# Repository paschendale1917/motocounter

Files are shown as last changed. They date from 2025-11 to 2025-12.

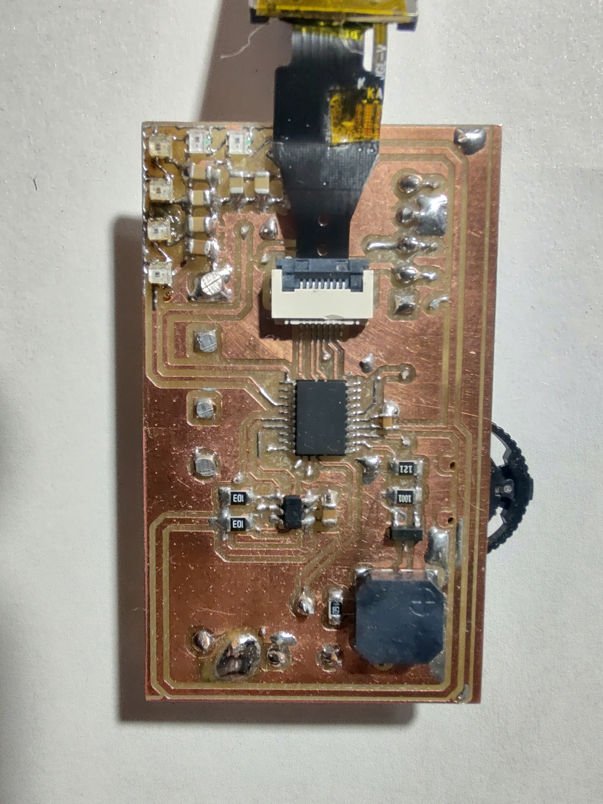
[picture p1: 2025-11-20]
IMG_20251120_144156860_HDR.jpg

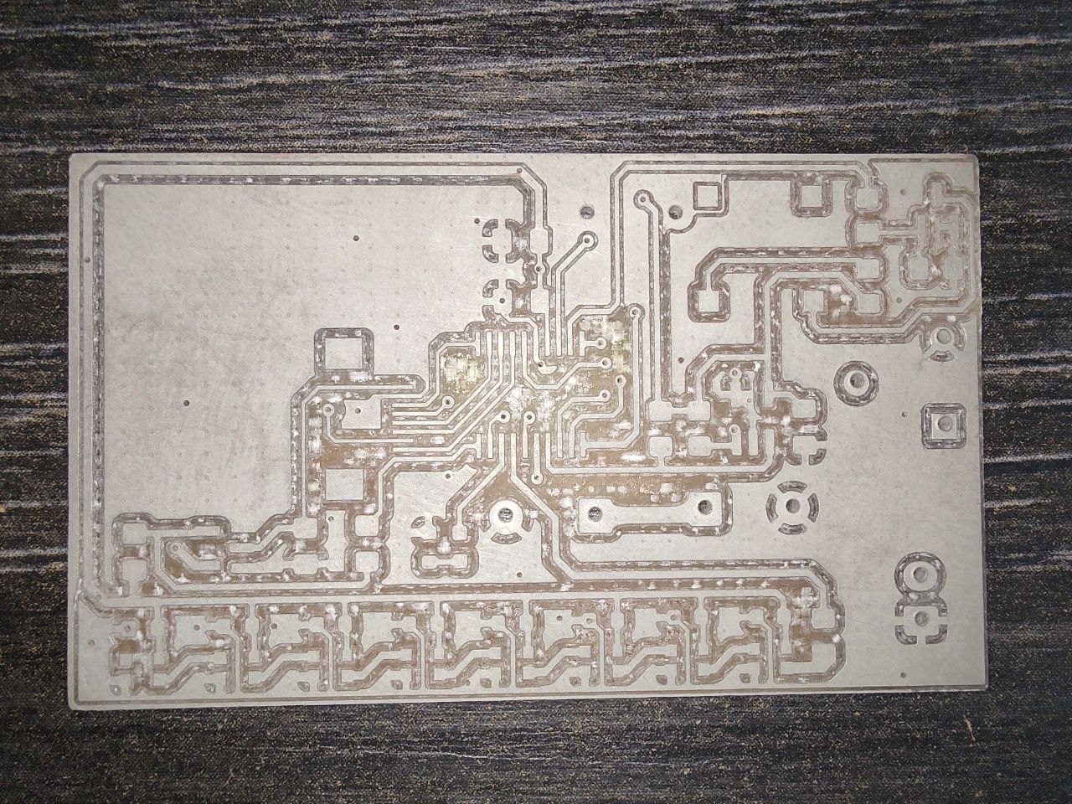
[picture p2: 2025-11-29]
photo_2025-11-30_00-51-48.jpg

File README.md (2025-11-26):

###	Счетчик моточасов с системой меню и управлением с помощью трехпозиционного слайдера

- **Микроконтроллер:** STM32G030F6P6 
- **Частота:** 64 МГц
- **IDE:** Keil uVision
- **Compiler:** v6.19
- **Язык:** C (Embedded)
- **Дисплей:** LCD ST7735 0.96" 80_160(IPS), 1.8" 128_160(TN), 0.85" 128_128(IPS)
- **Задействованная периферия:** таймеры, АЦП, SPI, I2C, DMA
- **Управление:** Трехпозиционная кнопка(слайдер)
- **Программатор:** ST-Link v2

###	Больше по дисплею
- можно любой на драйвере ST7735, но в дефайнах изменить разрешение, а также параметры LCD_HEIGHT_OFFSET и LCD_WIDTH_OFFSET выставить на 0, либо подобрать свои смещения
- возможно придется поиграться с регистрами MADCTL и INVON/INVOFF дисплея для установки верной ориентации и режима отображения цветов

###	Больше по периферии
- Нажатия слайдера обрабатываются в прерываниях таймера TIM1. Распознаются длительные и короткие нажатия
- Подсветка дисплея использует таймер TIM14  в режиме ШИМ
- Баззер использует таймер TIM17 в режиме ШИМ
- Счетчик организован на таймере TIM16
- Светодиоды WS2812 используют таймер TIM3 и канал 1 DMA1
- Вольтметр использует канал 10 мультиплексора АЦП и канал 2 DMA1
- Дисплей на SPI1
- EEPROM на I2C2
- WWDG

###	Клонирование репозитория
git clone https://github.com/paschendale1917/motocounter.git

###	Принцип работы:
После подачи питания устройство считывает из EEPROM настроечные константы, измеряет напряжение в бортовой сети и отображает на главном экране
 количество наработанных моточасов,напряжение бортовой сети и уставку моточасов, при достижении значения которой счетчик будет подавать светозвуковой сигнал.
При заведенном двигателе напряжение в бортовой сети повышается и при достижении порогового значения начинается отсчет времени.
Из меню можно настроить:
- величину порогового значения напряжения в бортовой сети для старта отсчета времени наработки
- уставку моточасов для подачи светозвуковой сигнализации при превышении счетчиком ее значения
- величину значения делителя(для того, чтобы не разбирать корпус и не подстраивать потенциометр на входе АЦП)
- цвет индикации превышения значения счетчика уставки моточасов
- яркость подсветки дисплея

При снижении напряжения питания ниже порогового значения прекращается отсчет времени и производится запись значения счетчика в EEPROM.
Все остальные настраиваемые константы также сохраняются в EEPROM.
Для того, чтобы при резком отключении питания была возможность сохранения всех настроек и значения счетчика, на входе по питанию установлены 2 конденсатора по 1000 мкФ. 
Через минуту после последней активности органов управления подсветка дисплея снижается до минимума.
 
###	Управление:
- вход в меню из главного экрана по длительному нажатию на центр слайдера
- выход из меню на скринсейвер по длительному отклонению слайдера влево
- вход в дочернее меню (child) по короткому нажатию на центр слайдера
- выход в родительское меню (parent) по длительному отклонению слайдера влево
- вход в обработчик пункта меню по короткому нажатию на центр слайдера
- выход из обработчика пункта меню по длительному отклонению слайдера влево
- согласие на системный ресет или сброс счетчика моточасов по длительному отклонению слайдера вправо

###	Краткое описание системы меню:
- Создана структура, в которой описаны связи пунктов меню(двунаправленные связные списки)между друг другом и обработчиками состояния меню(КА).
- В бесконечном цикле мониторится состояние переменной menustate(состояние меню),состояние флагов органов управления, отслеживаются изменения в состоянии меню,которое перерисовывается в соответствии с этими изменениями. 
	Также здесь работает функция display_pointer(pointer), которая меняет положение указателя в соответствии с активным пунктом меню(всегда указывает на него). Координаты указателя явно заданы в структуре. 
	Всё это происходит до того момента, пока переменная menustate не примет значение, соответствующее номеру одного из обработчиков.
- Как только зафиксировано изменение в состоянии органов управления(нажатие кнопки или вращение вала энкодера), то происходит действие в соответствии с заданным функционалом в process_menu() и связями, установленными 
	в структуре пункта меню-это либо вход в обработчик, либо в дочернее меню, либо перемещение по меню.
- При входе в обработчик в переменную menustate записывается его номер и таким образом process_menu() передает ему управление. Далее программа действует в соответствии с внутренней логикой обработчика.
- При выходе из обработчика в переменную menustate записывается значение, не соответствующее ни одному из номеров обработчиков, что возвращает управление функции process_menu().
- При старте в переменной menustate записан 0, что соответствует обработчику скринсейвера.
 
###	Внимание!
- Уверенно измеряет напряжение от 7 до 22 вольт, чтобы изменить диапазон, требуется подобрать иную элементную базу
- Нужно помнить, что чем выше входное напряжение, тем выше нагрев(78M05), поэтому беспроблемная эксплуатация возможна только на легковом 
 автомобиле с номинальным напряжением бортовой сети 12 в

###	TO DO:
- ...

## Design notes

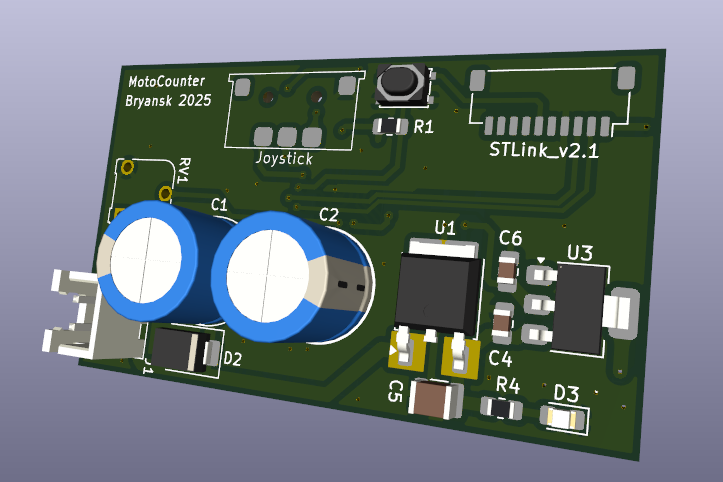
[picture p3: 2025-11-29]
Screenshot_2.png

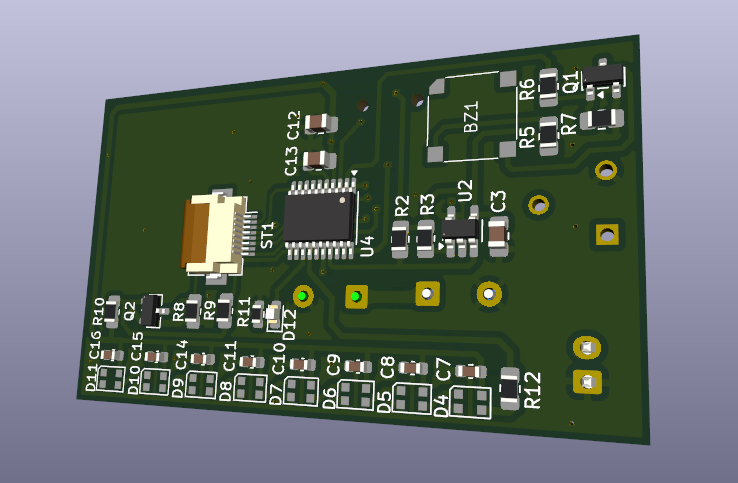
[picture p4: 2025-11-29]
Screenshot_1.png

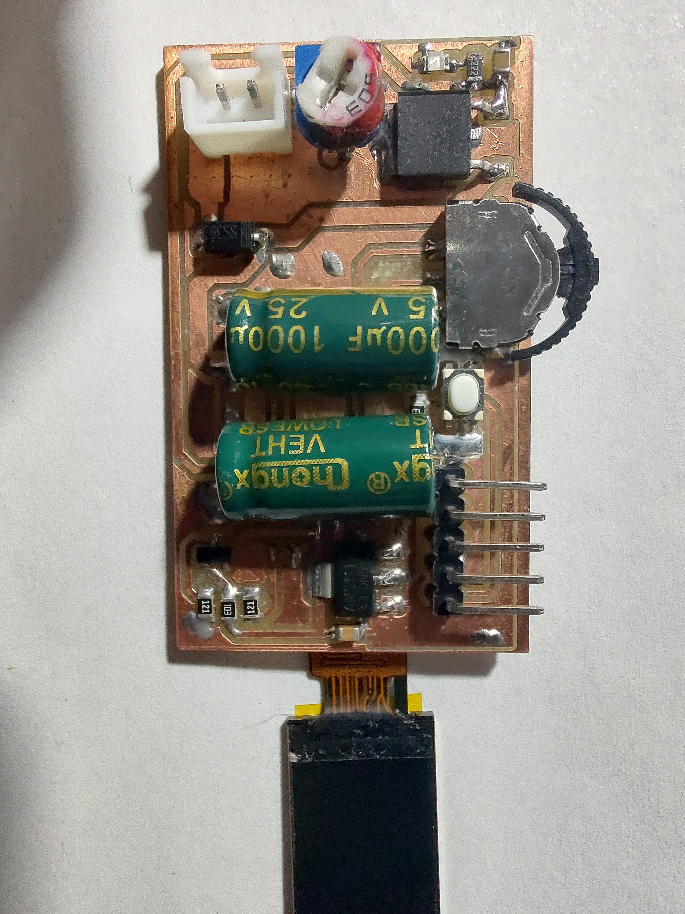
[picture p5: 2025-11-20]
IMG_20251120_144207942_HDR.jpg

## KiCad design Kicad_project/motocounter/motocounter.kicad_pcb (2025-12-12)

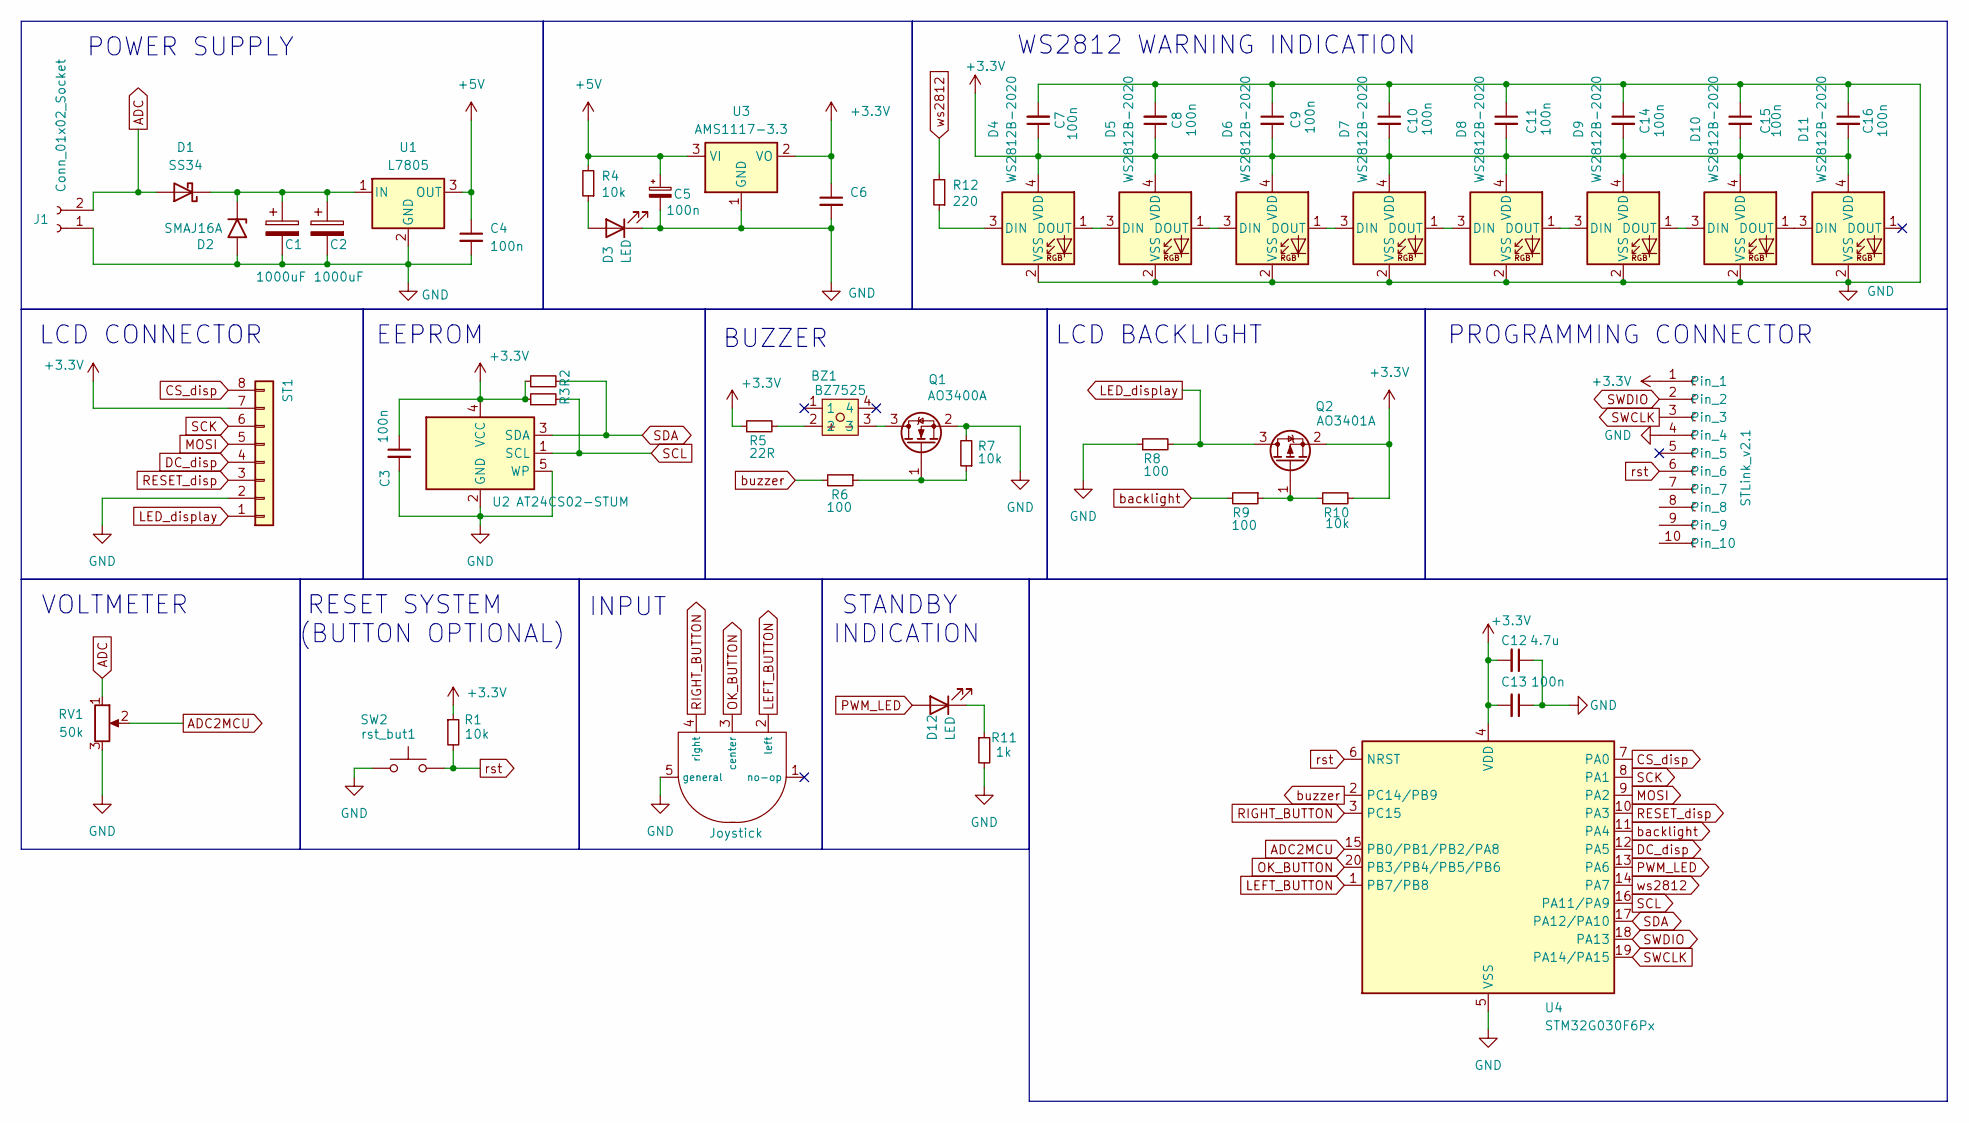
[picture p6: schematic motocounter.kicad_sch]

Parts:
BZ1: BZ7525; Buzzer_7525
C1, C2: 1000uF; CP_Radial_D10.0mm_P5.00mm
C3, C4, C13: 100n; C_0805_2012Metric_Pad1.18x1.45mm_HandSolder
C5: 100n; C_1210_3225Metric
C6: 2.2uF; C_0805_2012Metric_Pad1.18x1.45mm_HandSolder
C7, C8, C9, C10, C11, C14, C15, C16: 100n; C_0603_1608Metric
C12: 4.7u; C_0805_2012Metric_Pad1.18x1.45mm_HandSolder
D1: SS34; D_SMA
D2: SMAJ16A; D_SMB
D3: LED; LED_0805_2012Metric_Pad1.15x1.40mm_HandSolder
D4, D5, D6, D7, D8, D9, D10, D11: WS2812B-2020; LED_WS2812B-2020_PLCC4_2.0x2.0mm
D12: LED; LED_0603_1608Metric
J1: Conn_01x02_Socket; JST_XH_B2B-XH-A_1x02_P2.50mm_Vertical
Joystick: slide_button
Q1: AO3400A; SOT-23
Q2: AO3401A; SOT-23
R1, R2, R3, R4, R7, R10: 10k; R_0805_2012Metric_Pad1.20x1.40mm_HandSolder
R5: 22R; R_0805_2012Metric_Pad1.20x1.40mm_HandSolder
R6, R8, R9: 100; R_0805_2012Metric_Pad1.20x1.40mm_HandSolder
R11: 1k; R_0603_1608Metric
R12: 220; R_0805_2012Metric_Pad1.20x1.40mm_HandSolder
RV1: 50k; Potentiometer_Runtron_RM-065_Vertical
ST1: display; Hirose_FH12-8S-0.5SH_1x08-1MP_P0.50mm_Horizontal
STLink_v2.1: JST_SH_SM10B-SRSS-TB_1x10-1MP_P1.00mm_Horizontal
U1: L7805; TO-252-2
U2: AT24CS02-STUM; SOT-23-5_HandSoldering
U3: AMS1117-3.3; SOT-223-3_TabPin2
U4: STM32G030F6Px; TSSOP-20_4.4x6.5mm_P0.65mm
rst_but1: SW2; SW_SPST_PTS810

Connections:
+3.3V: C3.1, C6.1, C7.1, C8.1, C9.2, C10.2, C11.2, C12.2, C13.2, C14.2, C15.2, C16.2, D4.4 (VDD), D5.4 (VDD), D6.4 (VDD), D7.4 (VDD), D8.4 (VDD), D9.4 (VDD), D10.4 (VDD), D11.4 (VDD), Q2.2 (S), R1.1, R2.1, R3.1, R5.1, R10.2, ST1.7, STLink_v2.1.1, U2.4 (VCC), U3.2 (VO), U4.4 (VDD)
+5V: C4.1, C5.1, R4.2, U1.3 (OUT), U3.3 (VI)
ADC: D1.2 (A), J1.2, RV1.1
ADC2MCU: RV1.2, U4.15 (PB0/PB1/PB2/PA8)
CS_disp: ST1.8, U4.7 (PA0)
DC_disp: ST1.4, U4.12 (PA5)
GND: C1.2, C2.2, C3.2, C4.2, C5.2, C6.2, C7.2, C8.2, C9.1, C10.1, C11.1, C12.1, C13.1, C14.1, C15.1, C16.1, D2.2 (A2), D3.1 (K), D4.2 (VSS), D5.2 (VSS), D6.2 (VSS), D7.2 (VSS), D8.2 (VSS), D9.2 (VSS), D10.2 (VSS), D11.2 (VSS), J1.1, Joystick.5 (general), Q1.2 (S), R7.2, R8.1, R11.2, RV1.3, ST1.2, STLink_v2.1.4, U1.2 (GND), U2.2 (GND), U2.5 (WP), U3.1 (GND), U4.5 (VSS), rst_but1.1
LED_display: Q2.3 (D), R8.2, ST1.1
LEFT_BUTTON: Joystick.2 (left), U4.1 (PB7/PB8)
MOSI: ST1.5, U4.9 (PA2)
unnamed: BZ1.2, R5.2
unnamed: C1.1, C2.1, D1.1 (K), D2.1 (A1), U1.1 (IN)
unnamed: D3.2 (A), R4.1
unnamed: D4.3 (DIN), R12.1
unnamed: D4.1 (DOUT), D5.3 (DIN)
unnamed: D5.1 (DOUT), D6.3 (DIN)
unnamed: D6.1 (DOUT), D7.3 (DIN)
unnamed: D7.1 (DOUT), D8.3 (DIN)
unnamed: D8.1 (DOUT), D9.3 (DIN)
unnamed: D9.1 (DOUT), D10.3 (DIN)
unnamed: D10.1 (DOUT), D11.3 (DIN)
unnamed: D12.1 (K), R11.1
unnamed: BZ1.3, Q1.3 (D)
unnamed: Q1.1 (G), R6.1, R7.1
unnamed: Q2.1 (G), R9.1, R10.1
OK_BUTTON: Joystick.3 (center), U4.20 (PB3/PB4/PB5/PB6)
PWM_LED: D12.2 (A), U4.13 (PA6)
RESET_disp: ST1.3, U4.10 (PA3)
RIGHT_BUTTON: Joystick.4 (right), U4.3 (PC15)
SCK: ST1.6, U4.8 (PA1)
SCL: R3.2, U2.1 (SCL), U4.16 (PA11/PA9)
SDA: R2.2, U2.3 (SDA), U4.17 (PA12/PA10)
SWCLK: STLink_v2.1.3, U4.19 (PA14/PA15)
SWDIO: STLink_v2.1.2, U4.18 (PA13)
backlight: R9.2, U4.11 (PA4)
buzzer: R6.2, U4.2 (PC14/PB9)
rst: R1.2, STLink_v2.1.6, U4.6 (NRST), rst_but1.2
ws2812: R12.2, U4.14 (PA7)

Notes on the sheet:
EEPROM
PROGRAMMING CONNECTOR
POWER SUPPLY
LCD BACKLIGHT
VOLTMETER
WS2812 WARNING INDICATION
RESET SYSTEM (BUTTON OPTIONAL)
INPUT
BUZZER
STANDBY INDICATION
LCD CONNECTOR

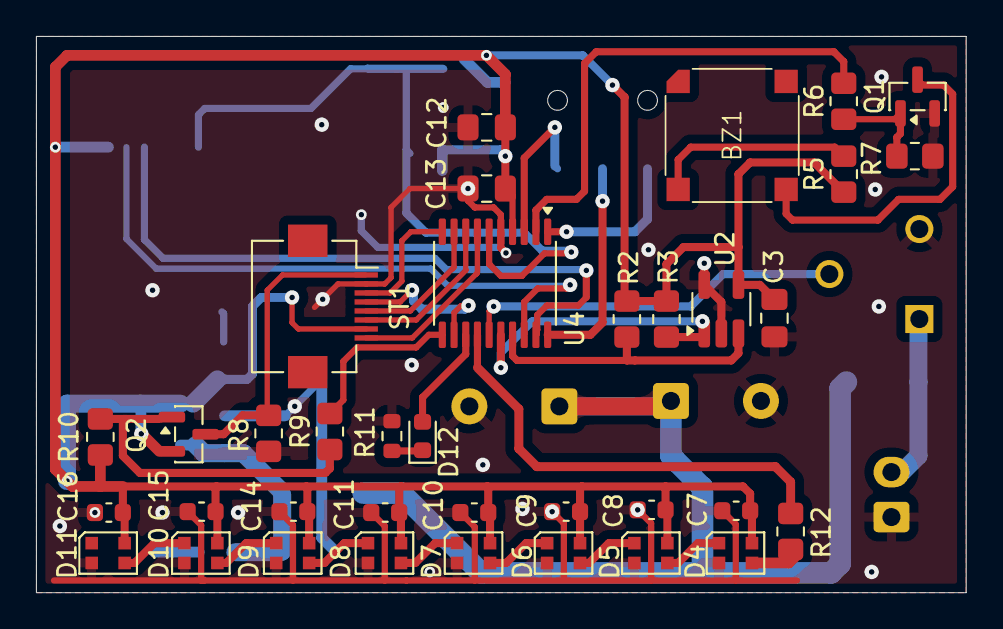
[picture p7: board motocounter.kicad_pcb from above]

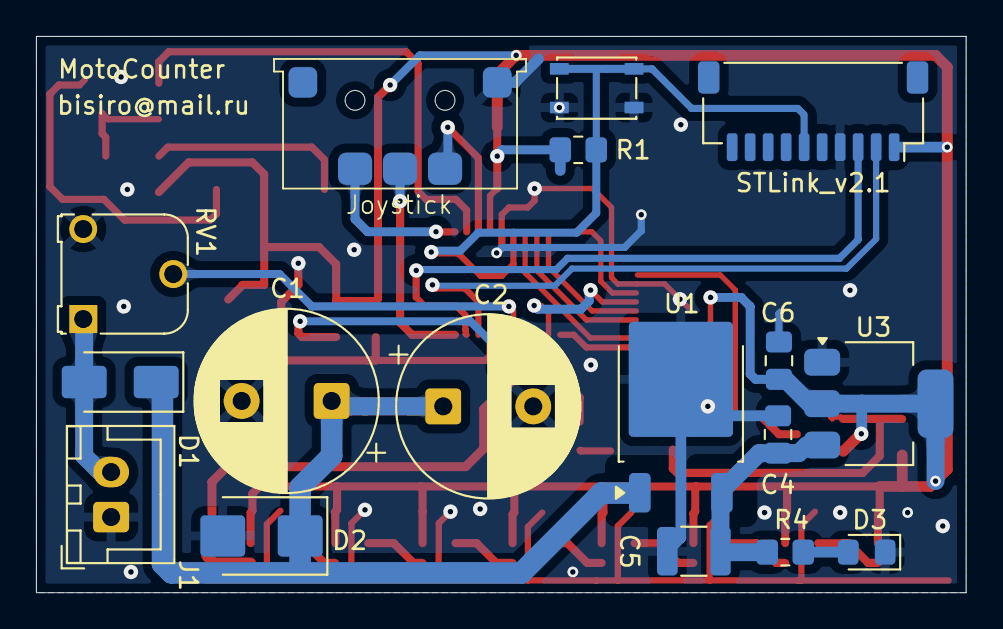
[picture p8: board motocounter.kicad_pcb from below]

Board: 2 copper layers, 51.6 x 30.9 mm, 53 parts (17 on the bottom side), 38 nets.

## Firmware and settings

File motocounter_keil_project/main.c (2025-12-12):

#include "main.h"

int main(void){
	hardware_init();
	menu_init(&main_menu_item_1);                                                       //инициализируем меню и устанавливаем указатель на первый пункт
	//display_current_menu(X_MENU_OFFSET,Y_MENU_OFFSET);                                  //отрисовываем начальное меню	
	
	while(1){
		
	switch(menustate){
			case MAINSCREEN:
				mainscreen_handler();	
				break;
			case  RESET:
			    reset_handler();
				break;
			case BACKLIGHT:
				backlight_handler();
				break;
			case ABOUT:
				about_handler();
				break;
			case FLASHLIGHT:
				flashlight_handler();
				break;
			case MOTOHOUR:
				motohour_handler();
				break;
			case RESETCOUNTER:
				resetcounter_handler();
				break;
			case DIVIDER:
				divider_handler();
				break;
			case VOLTFACTOR:
				voltfactor_handler();
				break;
			case REDCOMPONENT:
				redcomponent_handler();
				break;
			case GREENCOMPONENT:
				greencomponent_handler();
				break;
			case BLUECOMPONENT:
				bluecomponent_handler();
				break;
			default:
				menu_process();
//			for(uint16_t i=0;i<1000;i++){
//				set_led(i);
//				_delay_ms(200);
//			}
				break;
						
		}
	//policecolor_breathe();
		
	}
}

	

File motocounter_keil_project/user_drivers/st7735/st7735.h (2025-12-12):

#ifndef st77xx_H

#include "stm32g0xx.h"
#include "fonts.h"
#include "math.h"
#include <stdio.h>
#include <string.h>
#include "../spi/spi.h"
#include "../SysTick/systick_delay.h"
#include "../st7735_backlight/backlight.h"
#include "../ADC/ADC.h"

//#define STN_PORTRAIT
//#define STN_LANDSCAPE
//#define IPS_SQUARE
#define IPS_LANDSCAPE

#define COMMAND          												SET_BIT(GPIOA->BSRR,GPIO_BSRR_BR5)
#define DATA             												SET_BIT(GPIOA->BSRR,GPIO_BSRR_BS5)
#define RESET0           												SET_BIT(GPIOA->BSRR,GPIO_BSRR_BR3)
#define RESET1           												SET_BIT(GPIOA->BSRR,GPIO_BSRR_BS3)
#define START_Tx        												SET_BIT(GPIOA->BSRR,GPIO_BSRR_BR0) //chip select
#define STOP_Tx          												SET_BIT(GPIOA->BSRR,GPIO_BSRR_BS0)
#define ENABLE_SPI1														SET_BIT(SPI1->CR1,SPI_CR1_SPE)
#define DISABLE_SPI1													CLEAR_BIT(SPI1->CR1,SPI_CR1_SPE)

#define ST7735_HEIGHT                                                 	80
#define ST7735_WIDTH                                                  	160

#define ST7735_HEIGHT_OFFSET                                            1 //смещение китайского модуля по пикселам. на разных модулях по-разному
#define ST7735_WIDTH_OFFSET                                             26

#define WHITE     														0xFFFF
#define BLACK      														0x0000
#define BLUE        													0x001F
#define RED         													0xF800
#define MAGENTA     													0xF81F
#define GREEN       													0x07E0
#define CYAN        													0x7FFF
#define YELLOW      													0xFFE0
#define GRAY        													0X8430
#define BRED        													0XF81F
#define GRED       														0XFFE0
#define GBLUE      														0X07FF
#define BROWN      														0XBC40
#define BRRED       													0XFC07
#define DARKBLUE    													0X01CF
#define LIGHTBLUE   													0X7D7C
#define GRAYBLUE    													0X5458
#define ORANGE                                             				0xFA20

//макросы регистров контроллера дисплея st7735
#define ST7735_RDDMADCTL												0xB0
#define ST7735_NOP                                                      0x00
#define ST7735_SWRESET                                                  0x01
#define ST7735_RDDID                                                    0x04
#define ST7735_RDDST                                                    0x09
#define ST7735_SLPIN                                                    0x10
#define ST7735_SLPOUT                                                   0x11
#define ST7735_PTLON                                                    0x12
#define ST7735_NORON                                                    0x13
#define ST7735_INVOFF                                                   0x20
#define ST7735_INVON                                                    0x21
#define ST7735_DISPOFF                                                  0x28
#define ST7735_DISPON                                                   0x29
#define ST7735_CASET                                                    0x2A
#define ST7735_RASET                                                    0x2B
#define ST7735_RAMWR                                                    0x2C
#define ST7735_RAMRD                                                    0x2E
#define ST7735_PTLAR                                                    0x30
#define ST7735_COLMOD                                                   0x3A
#define ST7735_MADCTL                                                   0x36
#define ST7735_FRMCTR1                                                  0xB1
#define ST7735_FRMCTR2                                                  0xB2
#define ST7735_FRMCTR3                                                  0xB3
#define ST7735_INVCTR                                                   0xB4
#define ST7735_DISSET5                                                  0xB6
#define ST7735_RDDCOLMOD                                                0x0C
#define ST7735_PWCTR1                                                   0xC0
#define ST7735_PWCTR2                                                   0xC1
#define ST7735_PWCTR3                                                   0xC2
#define ST7735_PWCTR4                                                   0xC3
#define ST7735_PWCTR5                                                   0xC4
#define ST7735_VMCTR1                                                   0xC5
#define ST7735_RDID1                                                    0xDA
#define ST7735_RDID2                                                    0xDB
#define ST7735_RDID3                                                    0xDC
#define ST7735_RDID4                                                    0xDD
#define ST7735_PWCTR6                                                   0xFC
#define ST7735_GMCTRP1                                                  0xE0
#define ST7735_GMCTRN1                                                  0xE1
#define ST7735_SPI_TIMEOUT                                              100
#define MADCTL															0b01101000

#define BACKGROUND_ST7735(color)                                        draw_rect(0,0,ST7735_WIDTH,ST7735_HEIGHT,color)

#ifdef STN_PORTRAIT
	#define LCD_HEIGHT_SIZE                                                 160    //высота
	#define LCD_WIDTH_SIZE                                                  128		//ширина
	#define MADCTL															0b11000000
	#define LCD_WIDTH_OFFSET												0
	#define LCD_HEIGHT_OFFSET												0
#elif defined(STN_LANDSCAPE)
	#define LCD_HEIGHT_SIZE                                                 128    //высота
	#define LCD_WIDTH_SIZE                                                  160		//ширина
	#define MADCTL															0b01100000
	#define LCD_WIDTH_OFFSET												0
	#define LCD_HEIGHT_OFFSET												0
#elif defined(IPS_LANDSCAPE)
	#define LCD_HEIGHT_SIZE                                                 80    //высота
	#define LCD_WIDTH_SIZE                                                  160   //ширина
	#define MADCTL															0b01101000
	#define LCD_WIDTH_OFFSET												26
	#define LCD_HEIGHT_OFFSET												1
#elif defined(IPS_SQUARE)
	#define LCD_HEIGHT_SIZE                                                 128    //высота
	#define LCD_WIDTH_SIZE                                                  128   //ширина
	#define MADCTL															0b11001000
	#define LCD_WIDTH_OFFSET												1
	#define LCD_HEIGHT_OFFSET												2
#endif

#define BACKGROUND_COLOR                                                BLACK
#define FONT_COLOR        												BROWN

//#define BIGFONT_SPACE     												-4
//#define TINYFONT_SPACE    												1

#define TINYFONT

#ifdef BIGFONT
 #define SYSTEM_FONT       												BigFont
 #define SYSTEMFONT_SPACE 												BIGFONT_SPACE
#endif
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

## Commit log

2025-11-26 update 26/11
    [motocounter.kicad_pcb, motocounter.kicad_sch]
2025-11-29 update 30/11
    [motocounter.kicad_sch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]
2025-12-12 update 12/11
    [motocounter.kicad_pcb, motocounter.kicad_sch]
